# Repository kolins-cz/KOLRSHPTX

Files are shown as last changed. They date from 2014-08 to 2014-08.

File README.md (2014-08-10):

KOLRSHPTX
=========

Another version of OpenLRS 1W transmitter
---------

Photos of older version
https://picasaweb.google.com/m.kolinsky/KOLRSHPTX12

Everything is basicaly same as other OpenLRS transmitters.

Main features:
* Board fits in this nice (expensive) aluminum box http://www.tme.eu/en/details/akg-55-24-100-me/enclosures-with-panel/fischer-elektronik/akg-55-24-100-me/
* Power switch
* Two power supplies possible, Traco or Recom 7805-like DCDC or cheap 3A DCDC http://www.ebay.com/itm/Mini-3A-DC-DC-Converter-Adjustable-Step-Down-Power-Supply-Module-Replace-LM2596-/390877057320
* Adjustable voltage with cheap 3A DCDC = adjustable RF output power
* Reverse polarity protection
* Power from USB-serial may or may not be connected
* Standard 6pin ISP header
* Improved cooling of RFM23BP
* Open source!

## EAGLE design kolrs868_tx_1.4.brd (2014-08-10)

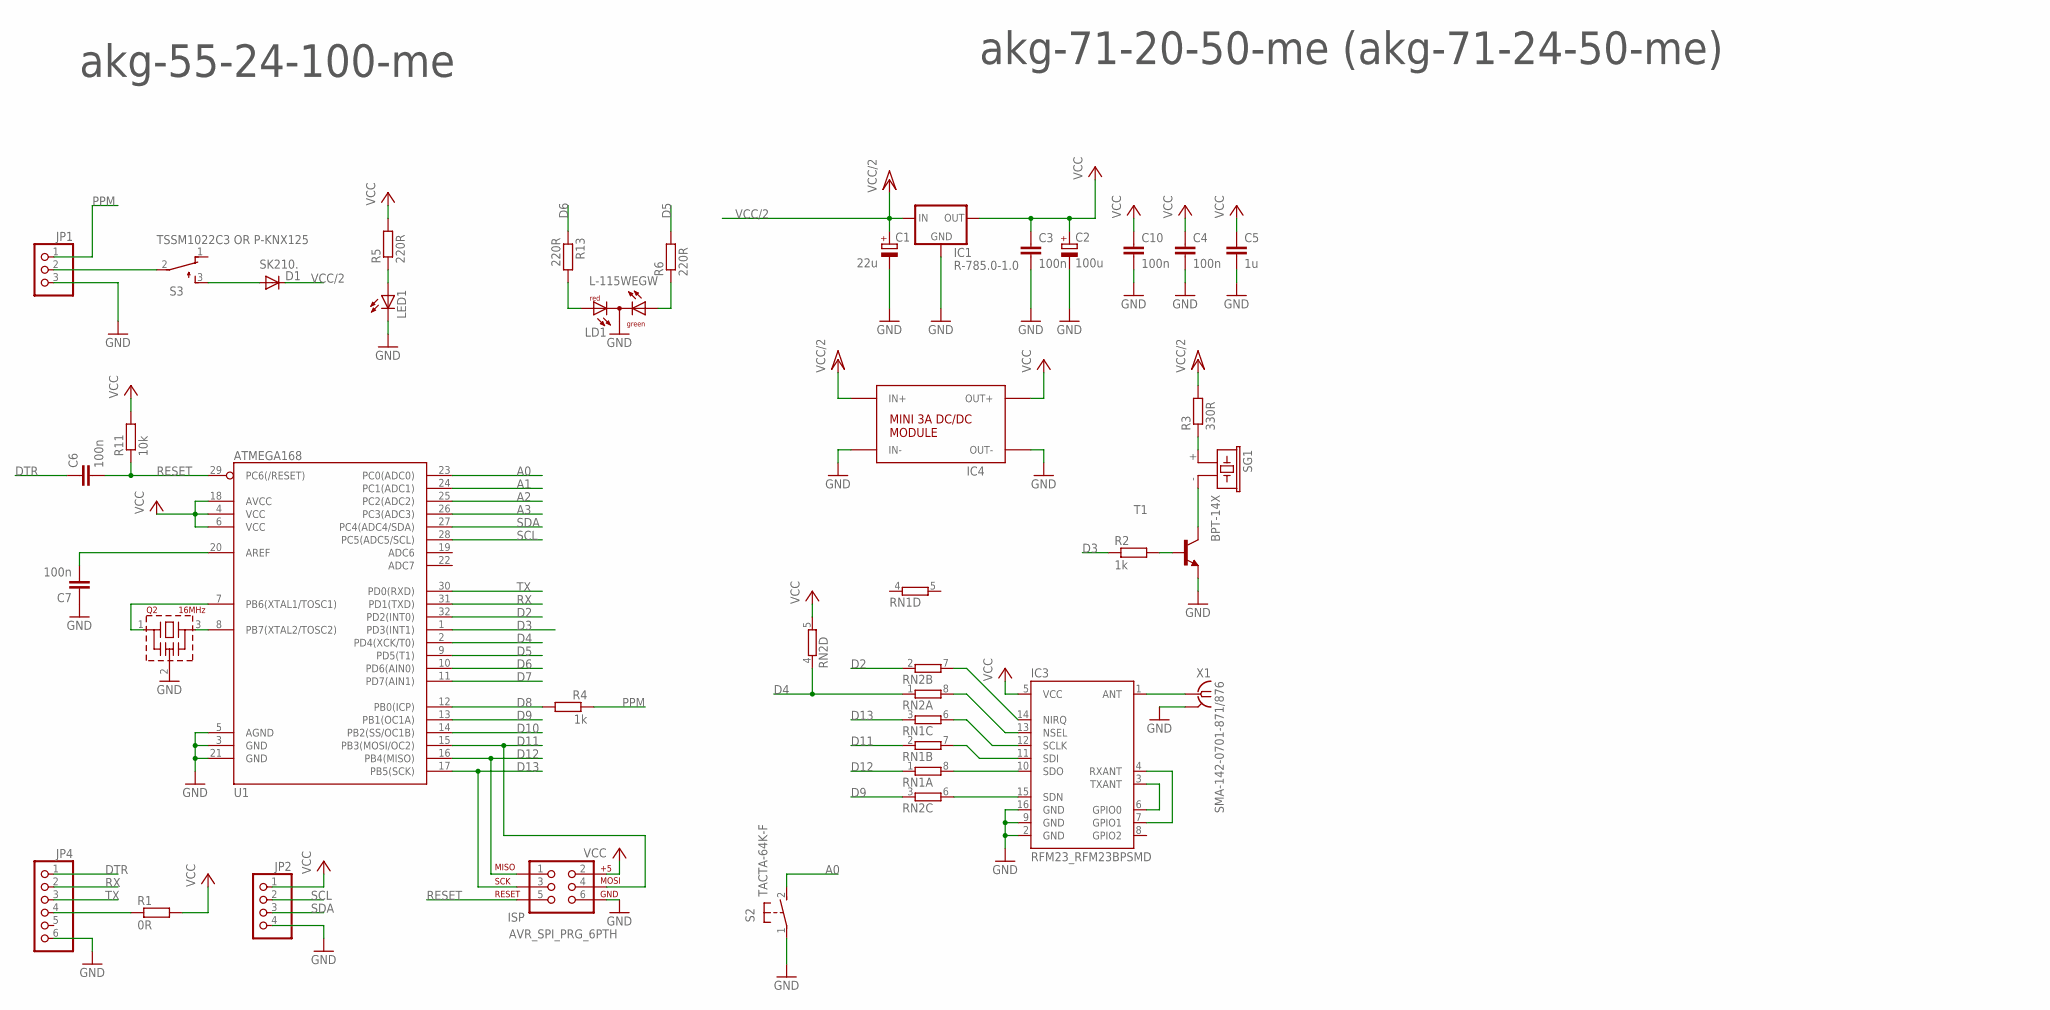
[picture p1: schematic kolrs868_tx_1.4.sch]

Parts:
C1: 22u; SMC_B
C2: 100u; SMC_B
C3, C4, C6, C7, C10: 100n; M0805
C5: 1u; C1206
D1: SK210.; SMB
IC1: R-785.0-1.0; 78XX_RECOM
IC3: RFM23_RFM23BPSMD; RFM23_RFM23BP-S2
IC4: MINI_3A_DCDC
ISP: AVR_SPI_PRG_6PTH; 2X3
JP1: PINHD-1X3; 1X03
JP2: PINHD-1X4; 1X04
JP4: PINHD-1X6; 1X06
LD1: L-115WEGW; DUOLED-C-5MM
LED1: LEDCHIPLED_1206; CHIPLED_1206
Q2: 16MHz; CSTLS_G8
R1: 0R; M0805
R2, R4: 1k; M0805
R3: 330R; M0805
R5, R6, R13: 220R; M0805
R11: 10k; M0805
RN1, RN2: 4R-NCAY16; CAY16
S2: TACTA-64K-F; B3F-31XX
S3: TSSM1022C3 OR P-KNX125; TL3XWO
SG1: BPT-14X; F/CM12P
T1: BC848-NPN-SOT23-BEC; SOT23-BEC
U1: ATMEGA168; TQFP32-08
X1: SMA-142-0701-871/876; J502-ND-142-0701-871/876

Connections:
A0: S2.2 (S), U1.23 (PC0(ADC0))
A1: U1.24 (PC1(ADC1))
A2: U1.25 (PC2(ADC2))
A3: U1.26 (PC3(ADC3))
D2: RN2.2 (1), U1.32 (PD2(INT0))
D3: R2.1, U1.1 (PD3(INT1))
D4: RN2.1, RN2.4 (1), U1.2 (PD4(XCK/T0))
D5: R6.2, U1.9 (PD5(T1))
D6: R13.1, U1.10 (PD6(AIN0))
D7: U1.11 (PD7(AIN1))
D8: R4.2, U1.12 (PB0(ICP))
D9: RN2.3 (1), U1.13 (PB1(OC1A))
D10: U1.14 (PB2(SS/OC1B))
D11: ISP.4, RN1.2 (1), U1.15 (PB3(MOSI/OC2))
D12: ISP.1, RN1.1, U1.16 (PB4(MISO))
D13: ISP.3, RN1.3 (1), U1.17 (PB5(SCK))
DTR: C6.1, JP4.1
GND: C1.-, C2.-, C3.2, C4.2, C5.2, C7.1, C10.2, IC1.GND, IC3.2 (GND), IC3.9 (GND), IC3.16 (GND), IC4.1 (IN-), IC4.2 (IN-), IC4.7 (OUT-), IC4.8 (OUT-), ISP.6, JP1.3, JP2.4, JP4.6, LD1.C, LED1.C, Q2.2 (VSS), S2.1, T1.E, U1.3 (GND), U1.5 (AGND), U1.21 (GND), X1.G@1 (GND), X1.G@2 (GND), X1.G@3 (GND), X1.G@4 (GND)
unnamed: C7.2, U1.20 (AREF)
unnamed: IC3.3 (TXANT), IC3.6 (GPIO0)
unnamed: IC3.4 (RXANT), IC3.7 (GPIO1)
unnamed: IC3.1 (ANT), X1.1
unnamed: LD1.AR, R13.2
unnamed: Q2.1, U1.7 (PB6(XTAL1/TOSC1))
unnamed: Q2.3, U1.8 (PB7(XTAL2/TOSC2))
unnamed: LD1.AX (AG), R6.1
unnamed: D1.A, S3.3 (S)
unnamed: R2.2, T1.B
unnamed: SG1.- (2), T1.C
unnamed: R3.1, SG1.+ (1)
unnamed: JP1.2, S3.2
unnamed: LED1.A, R5.1
unnamed: JP4.4, R1.1
unnamed: IC3.10 (SDO), RN1.8 (2)
unnamed: IC3.11 (SDI), RN1.7 (2)
unnamed: IC3.12 (SCLK), RN1.6 (2)
unnamed: IC3.15 (SDN), RN2.6 (2)
unnamed: IC3.13 (NSEL), RN2.8 (2)
unnamed: IC3.14 (NIRQ), RN2.7 (2)
PPM: JP1.1, R4.1
RESET: C6.2, ISP.5, R11.1, U1.29 (PC6(/RESET))
RX: JP4.2, U1.31 (PD1(TXD))
SCL: JP2.2, U1.28 (PC5(ADC5/SCL))
SDA: JP2.3, U1.27 (PC4(ADC4/SDA))
TX: JP4.3, U1.30 (PD0(RXD))
VCC: C2.+, C3.1, C4.1, C5.1, C10.1, IC1.OUT, IC3.5 (VCC), IC4.5 (OUT+), IC4.6 (OUT+), ISP.2, JP2.1, R1.2, R5.2, R11.2, RN2.5 (2), U1.4 (VCC), U1.6 (VCC), U1.18 (AVCC)
VCC/2: C1.+, D1.C, IC1.IN, IC4.3 (IN+), IC4.4 (IN+), R3.2

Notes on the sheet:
akg-71-20-50-me (akg-71-24-50-me)
akg-55-24-100-me

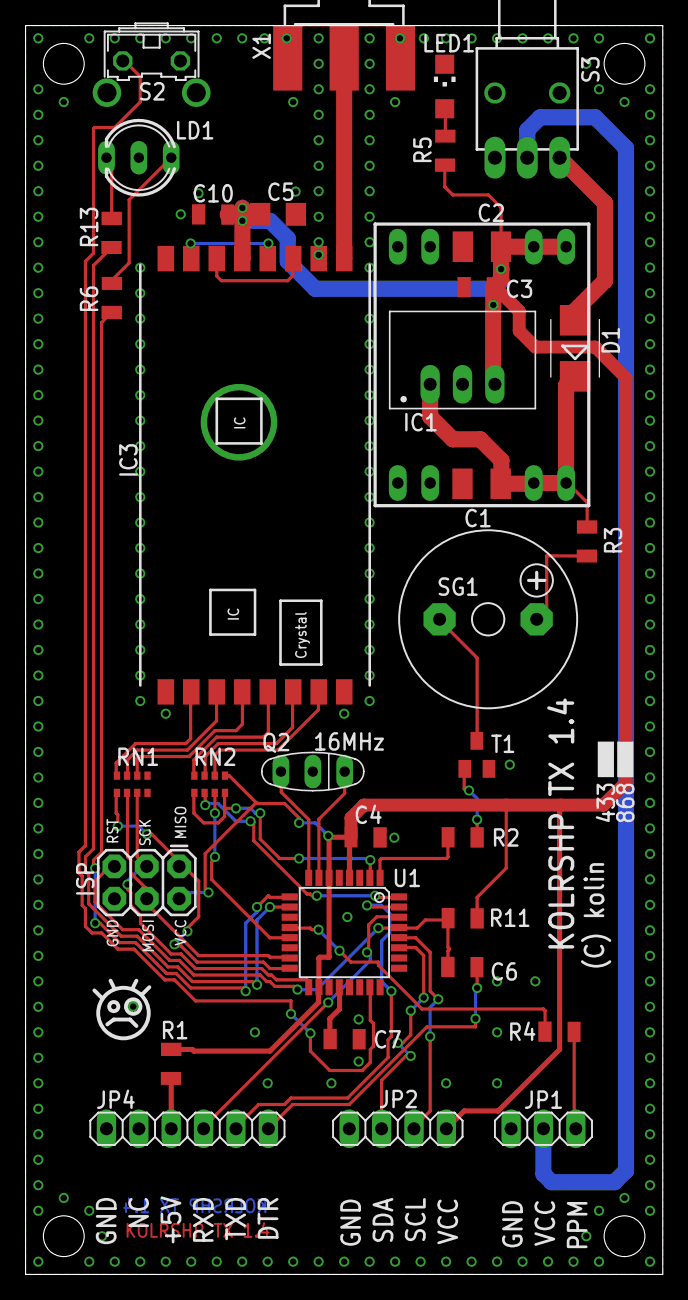
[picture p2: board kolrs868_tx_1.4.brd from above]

Board: 2 copper layers, 50.0 x 98.0 mm, 35 parts (0 on the bottom side), 42 nets.
